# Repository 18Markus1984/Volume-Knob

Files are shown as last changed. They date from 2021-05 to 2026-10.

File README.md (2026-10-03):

# Volume Knob V2 (USB-C)

A compact USB volume knob based on an **Arduino Pro Micro (USB-C)**. Turn it to change your computer's volume, click to mute – and eight RGB LEDs under a transparent ring give visual feedback with selectable colors and animations.

The knob shows up as a standard USB media keyboard, so it works on Windows, macOS and Linux without any drivers.



**3D-printable parts, photos and more:** [Printables – Volume Knob V2 (USB-C)](https://www.printables.com/model/154855-volume-knob-v2-usb-c)

---

## Features

- Volume up / down by turning the knob, mute by clicking it
- 8 addressable RGB LEDs (SK6812) behind a clear printed ring
- 25 selectable colors
- Several LED animation modes
- Color and mode are stored in EEPROM and survive unplugging
- USB-C, plug & play (USB HID consumer control)
- Roughly **€20** in parts per knob

## Bill of Materials

| Qty | Part | Notes |
|---:|---|---|
| 1 | Arduino Pro Micro (ATmega32U4, **USB-C**) | 5 V / 16 MHz |
| 8 | SK6812 RGB LED, 5050 package | WS2812B-compatible |
| 1 | ALPS rotary encoder with push switch | |
| 1 | 10 kΩ resistor | |
| 1 | Custom PCB | KiCad project and Gerbers in this repo |
| 4 | M3 × 16 screws | |
| 4 | M3 threaded inserts | |
| – | PLA + clear/transparent filament | for the housing and the light ring |

## 3D Printing

All parts print fine in **PLA**. Print the **light ring in transparent filament** so the LEDs shine through. The bottom can optionally be printed with a decorative pattern – an *Octagram Spiral* top/bottom surface pattern looks great.

The print files are on [Printables](https://www.printables.com/model/154855-volume-knob-v2-usb-c); the source CAD files (Autodesk Inventor, STEP, STL) are in [`ProMicroKiCad-master/VolumeKnob/3DObjekt`](ProMicroKiCad-master/VolumeKnob/3DObjekt).

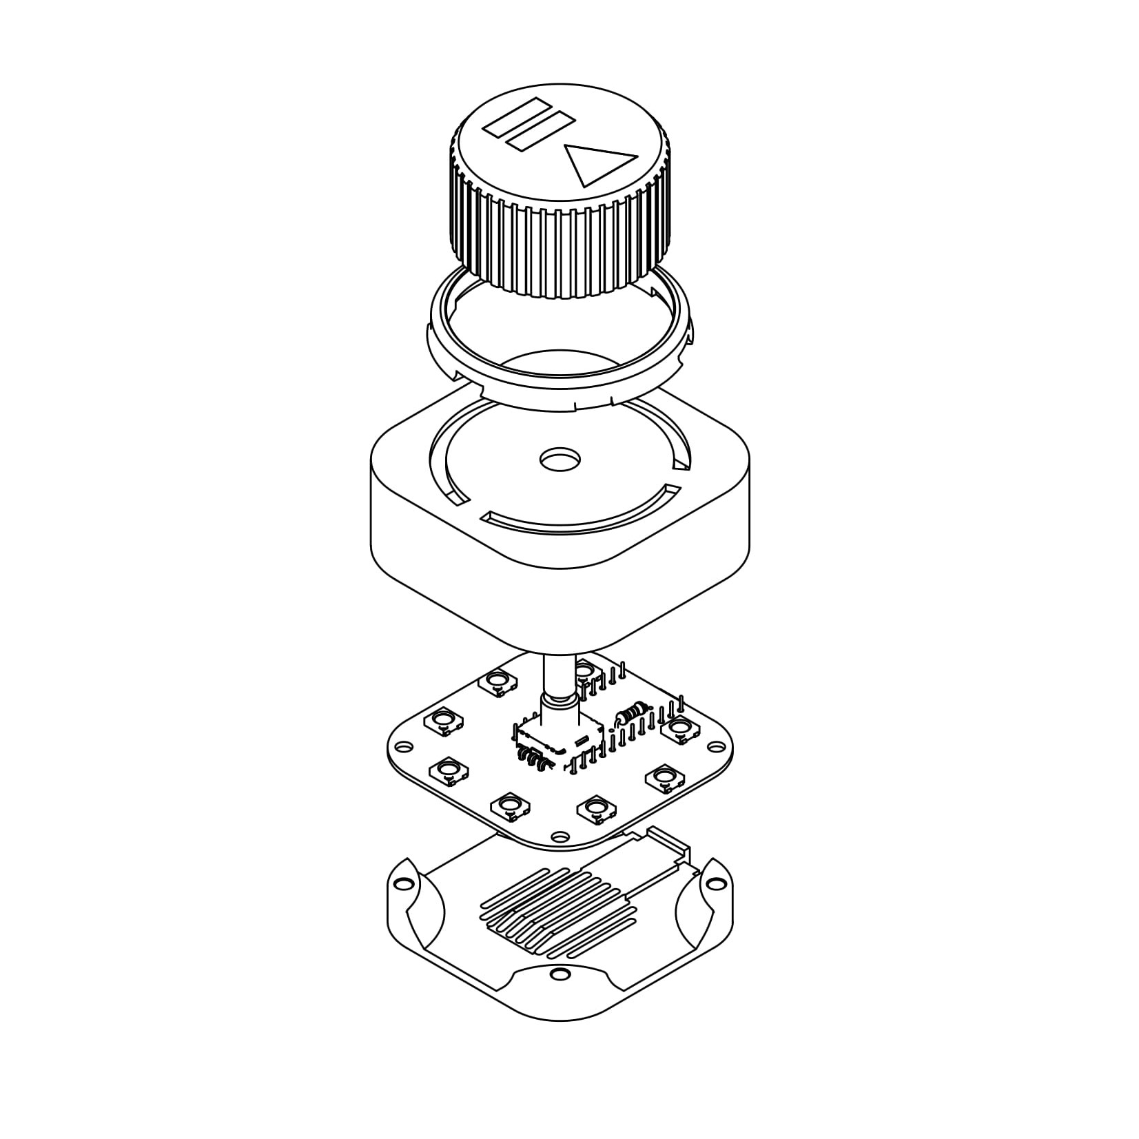
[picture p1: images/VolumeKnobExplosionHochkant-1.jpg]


## Assembly

1. Solder the rotary encoder, the Arduino Pro Micro and the resistor onto the PCB.
2. Melt the four M3 threaded inserts into the holes of the bottom housing.
3. Snap the transparent ring into the housing (snap-fit, no glue needed).
4. Fasten the PCB assembly with the four M3 screws.
5. Press the knob onto the encoder shaft – it's a press fit, no adhesive required.

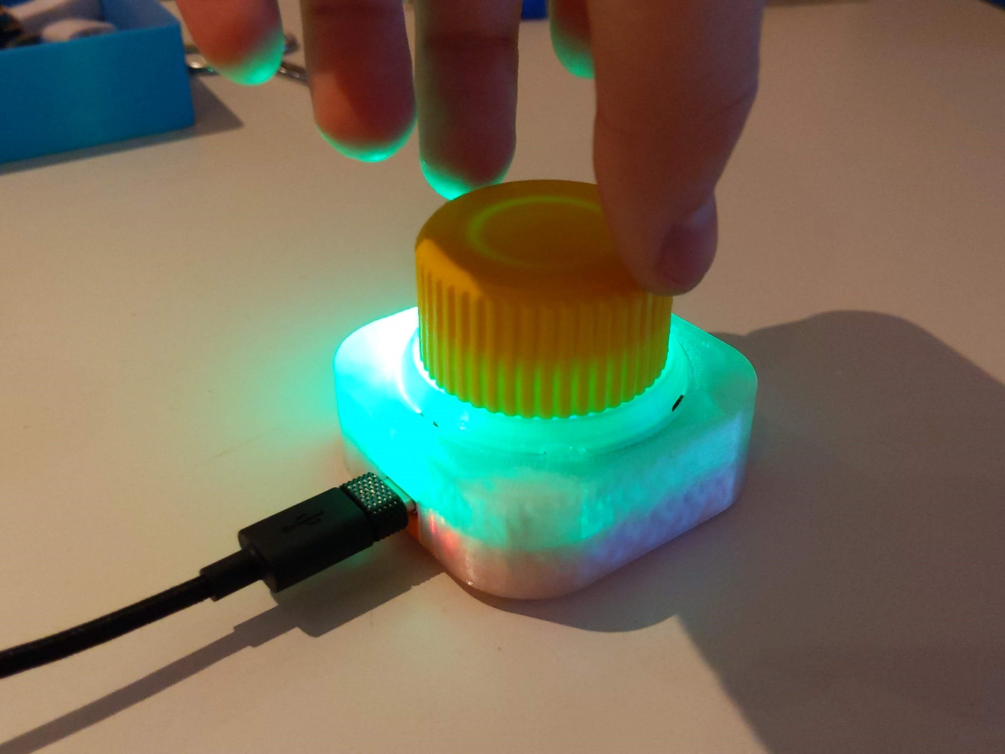
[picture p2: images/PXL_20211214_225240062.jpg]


## Wiring

| Pro Micro pin | Connected to |
|---:|---|
| 7 | LED data in (SK6812 chain) |
| 6 | Encoder CLK (A) |
| 5 | Encoder DT (B) |
| 2 | Encoder push button (SW) |

## Firmware

The sketch is located at [`volumeKnob/volumeKnob.ino`](volumeKnob/volumeKnob.ino).

### Required libraries

Install via the Arduino Library Manager:

- [HID-Project](https://github.com/NicoHood/HID) by NicoHood – USB media keys
- [Encoder](https://github.com/PaulStoffregen/Encoder) by Paul Stoffregen
- [Adafruit NeoPixel](https://github.com/adafruit/Adafruit_NeoPixel)
- [OneButton](https://github.com/mathertel/OneButton) by Matthias Hertel
- EEPROM (included with the Arduino IDE)

### Upload

1. Select the board **Arduino Leonardo** (or *SparkFun Pro Micro, 5 V / 16 MHz* if you have the SparkFun board package installed).
2. Choose the correct port and upload.

If you use a different number of LEDs, change `NUMPIXELS` at the top of the sketch.

> **Note:** On startup the knob sends 50× *Volume Down* followed by 2× *Volume Up*, so your system volume is set to a low, known level every time it is plugged in.

## Usage

| Action | Volume mode | Color menu | Mode menu |
|---|---|---|---|
| **Turn** | Volume up / down | Browse the 25 colors | Browse the animation modes |
| **Click** | Mute / unmute | Save color & go back | Save mode & go back |
| **Long press** | Open color menu | Open mode menu | Back to volume mode (without saving) |

Two encoder detents equal one volume step.

### LED modes

- **Single pixel** – one LED follows the knob and slowly fades out
- **Rainbow fade** – all LEDs fade through the color wheel
- **Rainbow wheel** – a rotating rainbow around the ring
- **Pixel trail** – three LEDs follow the knob and stay lit

In the mode menu the modes are arranged in groups around the ring, separated by a dark position.

## Repository Structure

```
Volume-Knob/
├── volumeKnob/volumeKnob.ino          # current firmware (V2)
├── images/                            # photos and GIFs
└── ProMicroKiCad-master/
    ├── VolumeKnob/
    │   ├── VolumeKnob.kicad_pro/_sch/_pcb   # KiCad project of the PCB
    │   ├── jlcpcb/                     # Gerber, BOM & CPL for JLCPCB
    │   ├── Gerber/                     # older Gerber revisions
    │   ├── 3DObjekt/                   # Inventor / STEP / STL files
    │   └── Code/                       # older sketches and test code
    └── ProMicroKiCad-master/           # Pro Micro KiCad library
```

## Gallery

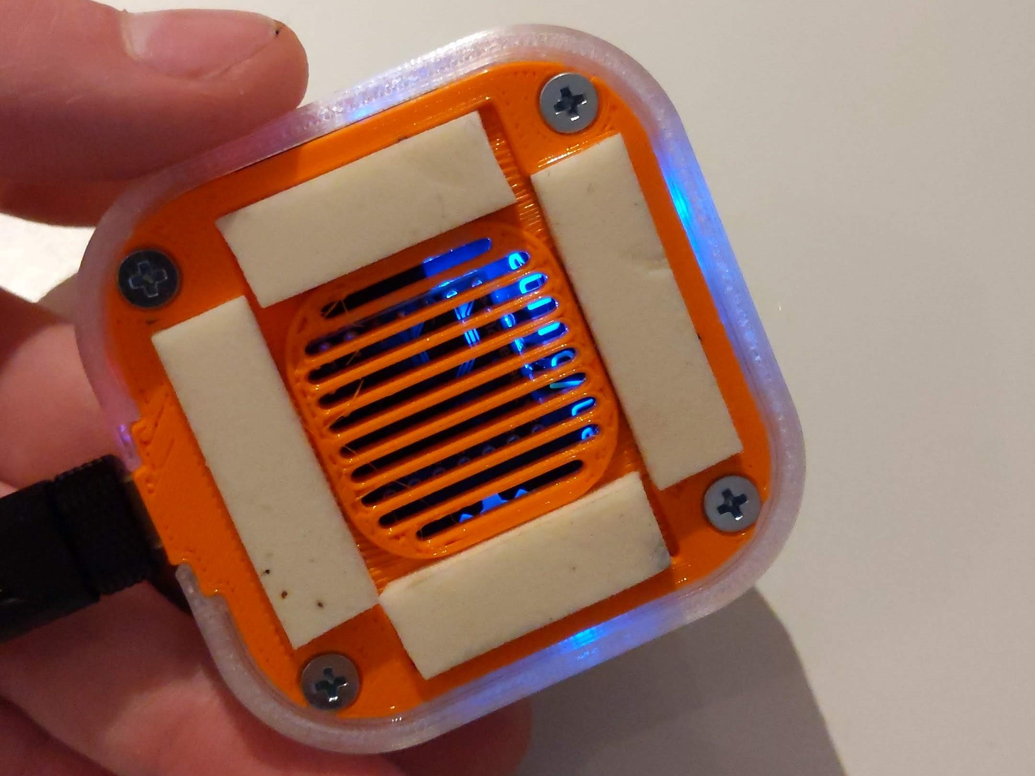
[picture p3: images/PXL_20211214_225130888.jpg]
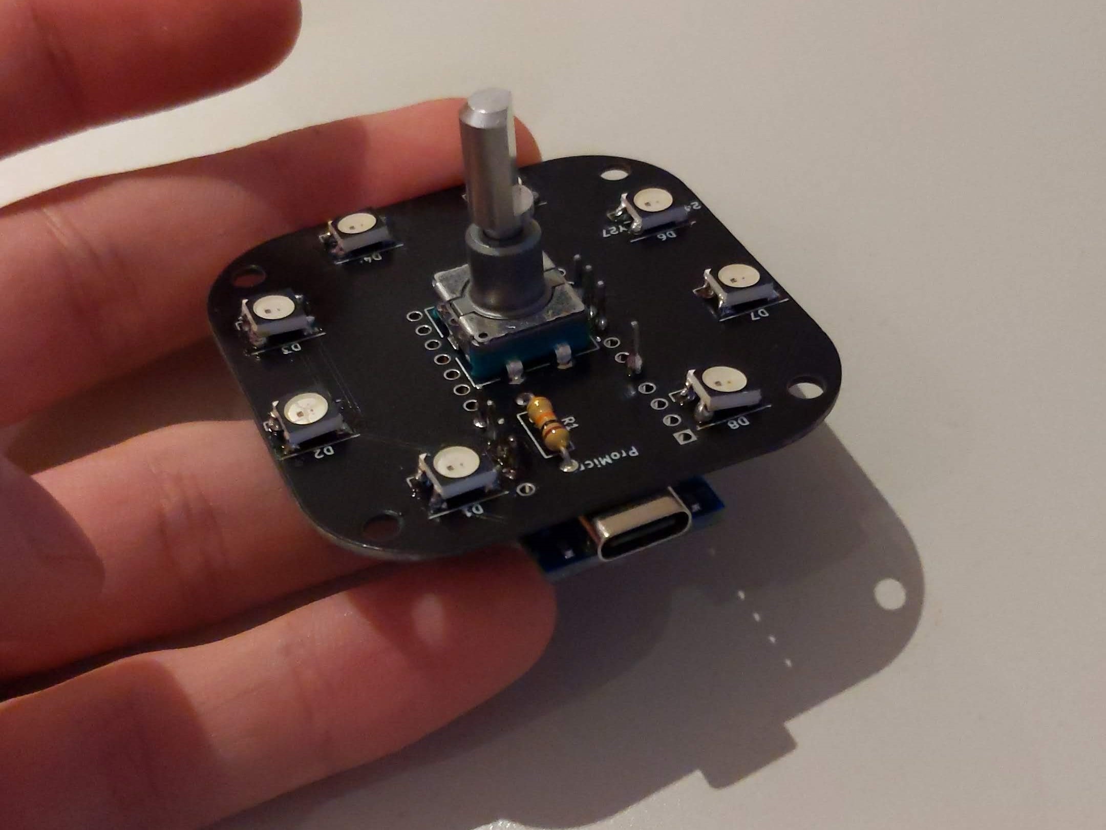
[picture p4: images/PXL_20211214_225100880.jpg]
 

## Version 1

The first version used a micro-USB Pro Micro, single-color green LEDs and a hand-wired build (8× green LEDs, 2× 10 kΩ resistors). Using individual LEDs instead of a ring PCB wasn't the best idea – it took some hot glue to hold everything in place – which led to the V2 with a custom PCB, RGB LEDs and USB-C.

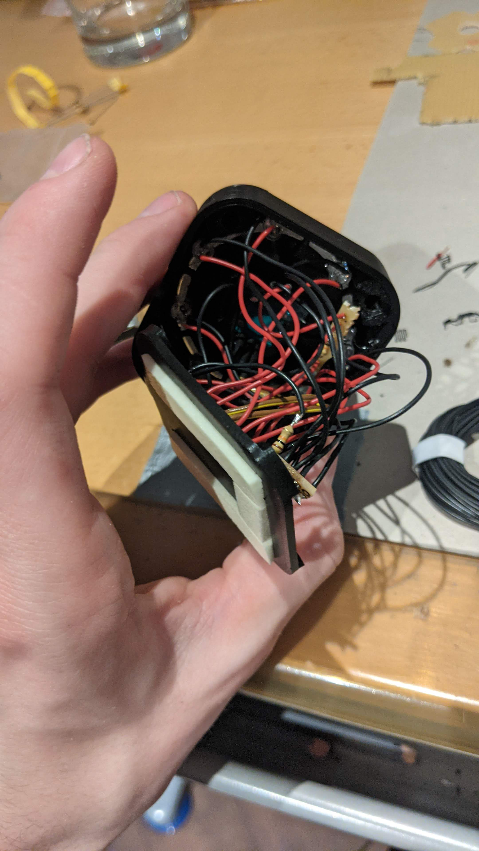
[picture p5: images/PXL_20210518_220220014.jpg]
 

---

Made by **Max Siebenschläfer** – find more projects on [Printables](https://www.printables.com/model/154855-volume-knob-v2-usb-c).

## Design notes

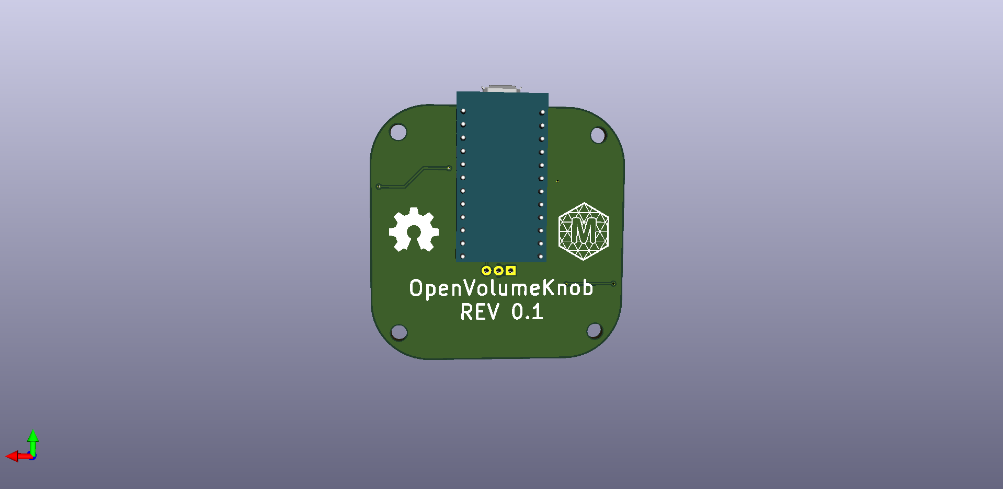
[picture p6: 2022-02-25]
ProMicroKiCad-master/VolumeKnob/images/VolumeKnob2.png

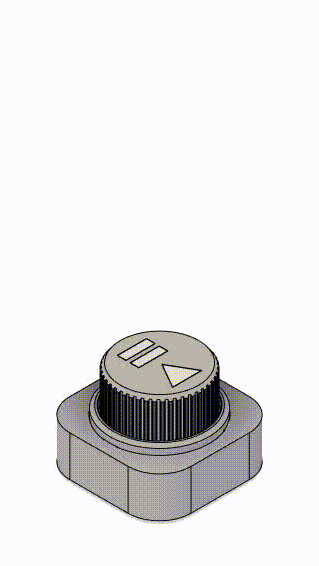
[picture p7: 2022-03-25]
images/ezgif-1-fd4612bca2.gif

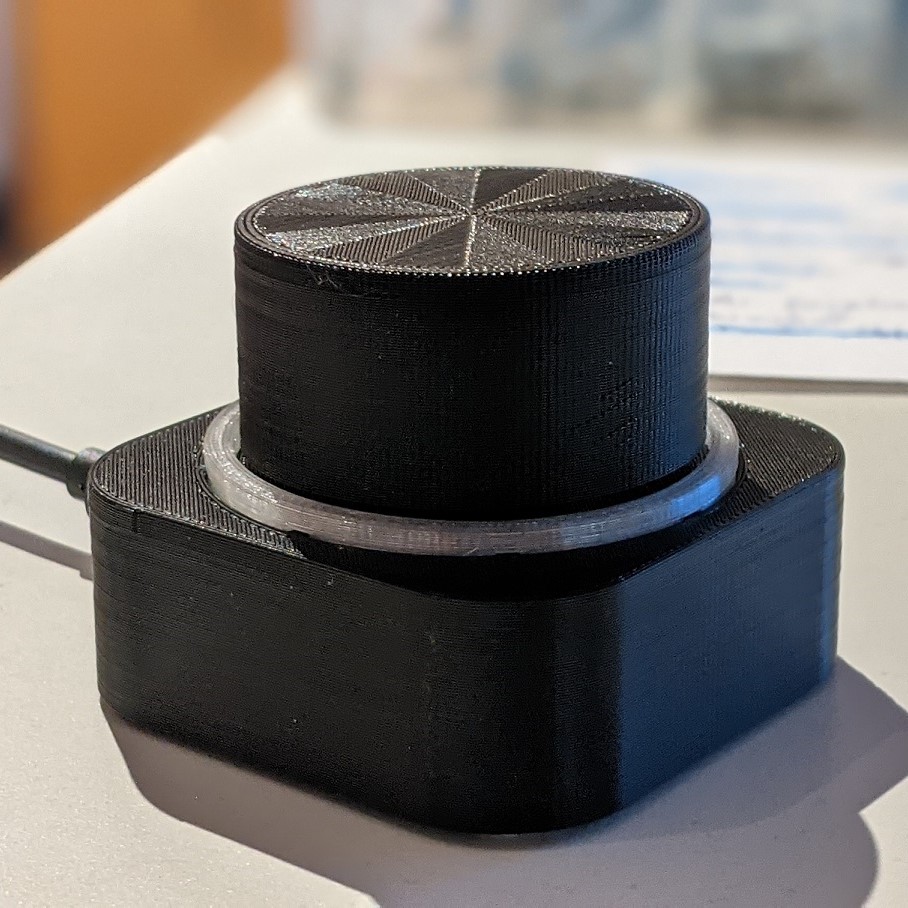
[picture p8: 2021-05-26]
images/PXL_20210518_190823981.PORTRAIT.jpg

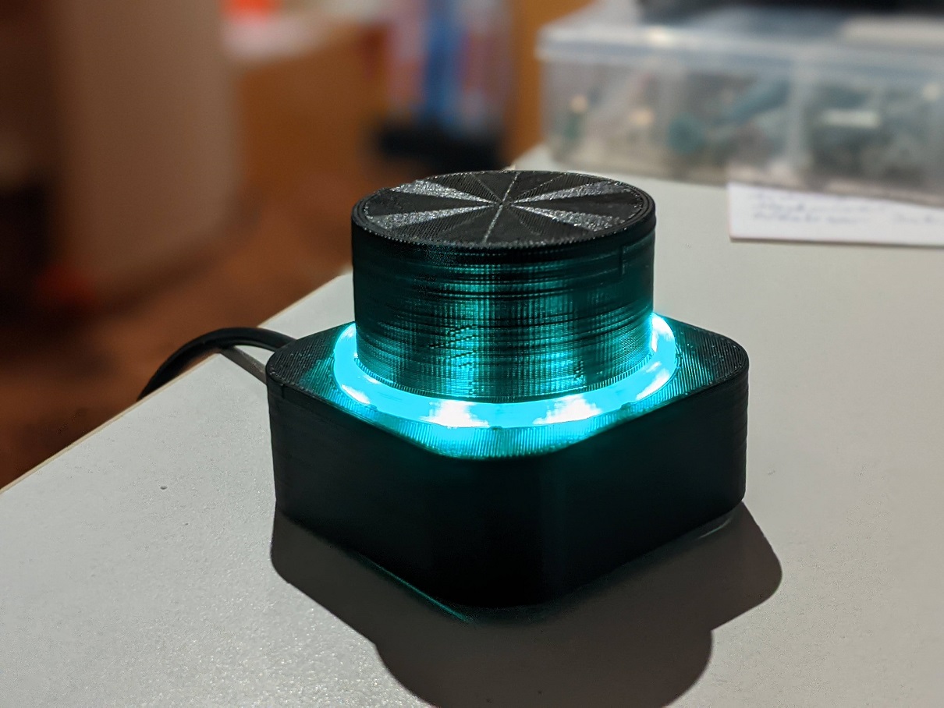
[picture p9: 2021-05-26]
images/PXL_20210525_201555468.PORTRAIT.jpg

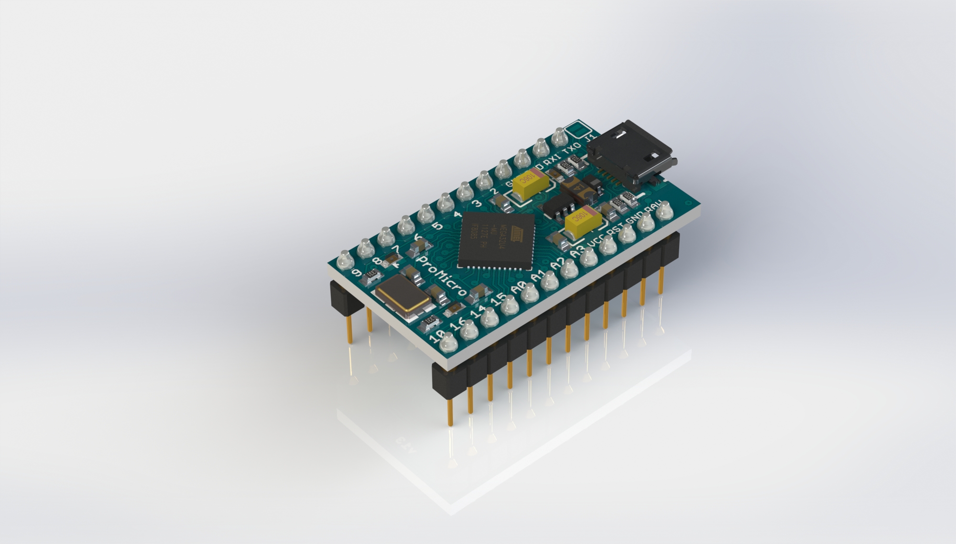
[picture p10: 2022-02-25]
ProMicroKiCad-master/arduino-pro-micro-1.snapshot.1/PROMICRO 1.JPG

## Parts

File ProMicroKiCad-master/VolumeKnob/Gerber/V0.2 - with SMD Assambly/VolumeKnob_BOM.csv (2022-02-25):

Comment | Designator | Footprint | LCSC
SK6812 | D1,D2,D3,D4,D5,D6,D7,D8 | LED_SMD:LED_SK6812_PLCC4_5.0x5.0mm_P3.2mm
10 kΩ | R1 | Resistor_THT:R_Axial_DIN0207_L6.3mm_D2.5mm_P10.16mm_Horizontal
Rotary_Encoder_Switch | SW1 | Rotary_Encoder:RotaryEncoder_Alps_EC12E-Switch_Vertical_H20mm
ProMicro | U1 | promicro:ProMicro-NoSilk

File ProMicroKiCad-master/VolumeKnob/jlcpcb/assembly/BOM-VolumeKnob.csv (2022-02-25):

Comment | Designator | Footprint | LCSC
WS2812B | D1,D10,D11,D12,D13,D14,D15,D16,D17,D18,D19,D2,D20,D21,D22,D23,D24,D25,D26,D27,D28,D29,D3,D30,D31,D32,D33,D34,D35,D36,D4,D5,D6,D7,D8,D9 | LED_WS2812B_PLCC4_5.0x5.0mm_P3.2mm | C114586

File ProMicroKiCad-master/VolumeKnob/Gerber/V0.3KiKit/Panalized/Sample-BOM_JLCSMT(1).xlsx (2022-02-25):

Comment | Designator | Footprint | JLCPCB Part #（optional）
WS2812B | D1,D2,D3,D4,D5,D6,D7,D8,D9 | LED_SMD:LED_WS2812B_PLCC4_5.0x5.0mm_P3.2mm | C114586

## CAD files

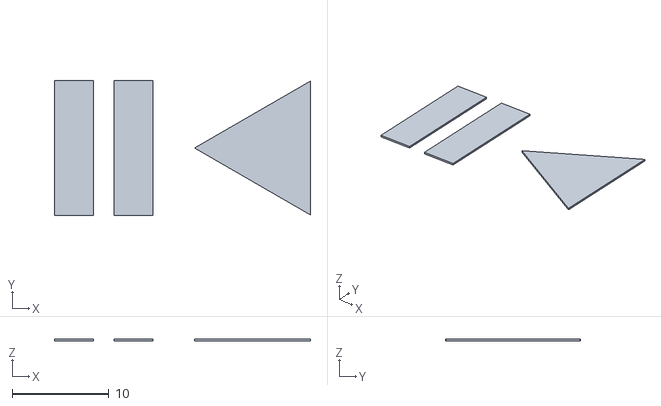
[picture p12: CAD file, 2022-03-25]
ProMicroKiCad-master/VolumeKnob/3DObjekt/Pause.stl
26.4 x 13.9 x 0.2

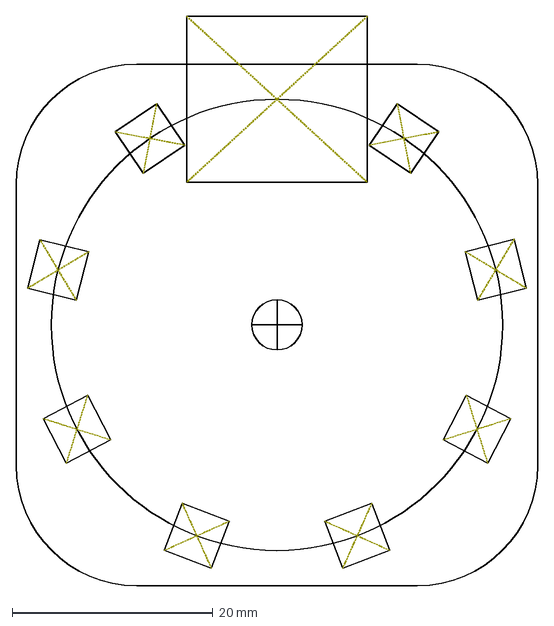
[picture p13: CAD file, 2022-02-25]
ProMicroKiCad-master/VolumeKnob/BackUpBevorKiKit/Grundform.dxf
52.0 x 56.8 mm

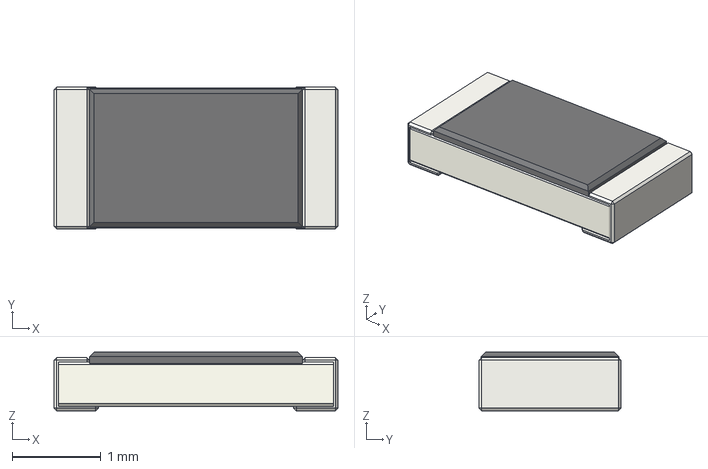
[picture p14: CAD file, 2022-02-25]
ProMicroKiCad-master/VolumeKnob/kicad3Dmodels-master/kicad3Dmodels-master/generated/Resistors/Chip/RESC3216x66_EIA1206_METRIC3216.step
3.20 x 1.60 x 0.66 mm

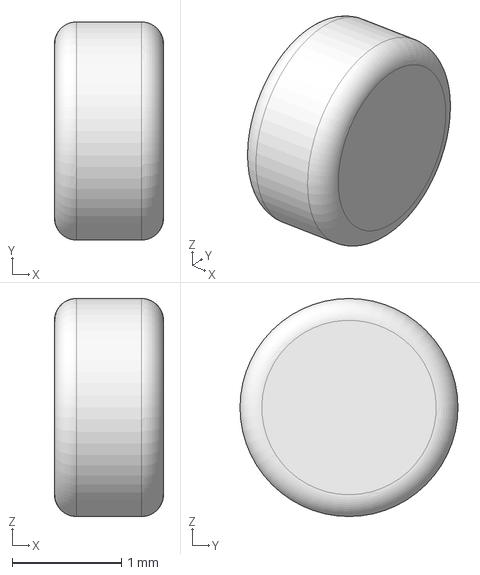
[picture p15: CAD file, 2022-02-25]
ProMicroKiCad-master/VolumeKnob/kicad3Dmodels-master/kicad3Dmodels-master/generated/Resistors/Film_Carbon/unitary_ring.fcstd
1.00 x 2.00 x 2.00 mm

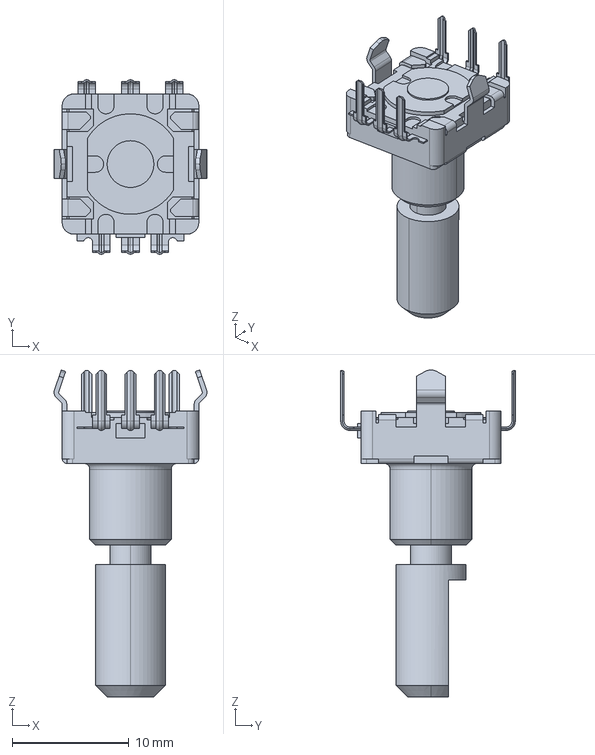
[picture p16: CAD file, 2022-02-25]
ProMicroKiCad-master/VolumeKnob/Objekts/RotaryEncoder.stp
13.1 x 15.0 x 28.0 mm

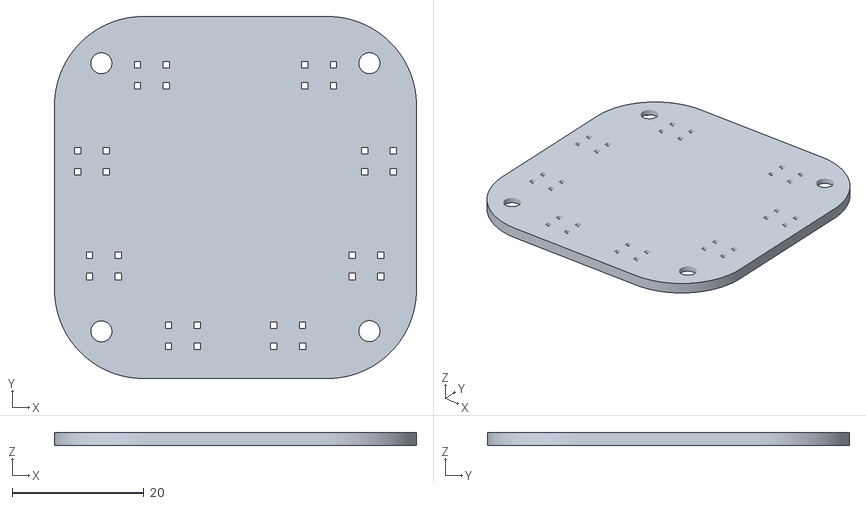
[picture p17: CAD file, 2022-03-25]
ProMicroKiCad-master/VolumeKnob/3DObjekt/Stencil.stl
55.0 x 55.0 x 2.00

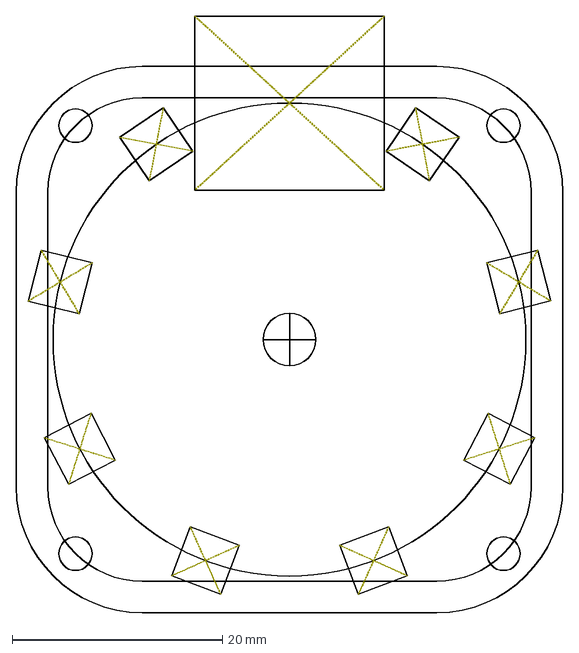
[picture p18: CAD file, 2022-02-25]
ProMicroKiCad-master/VolumeKnob/BackUpBevorKiKit/GrundformBorlöcher.dxf
52.0 x 56.8 mm

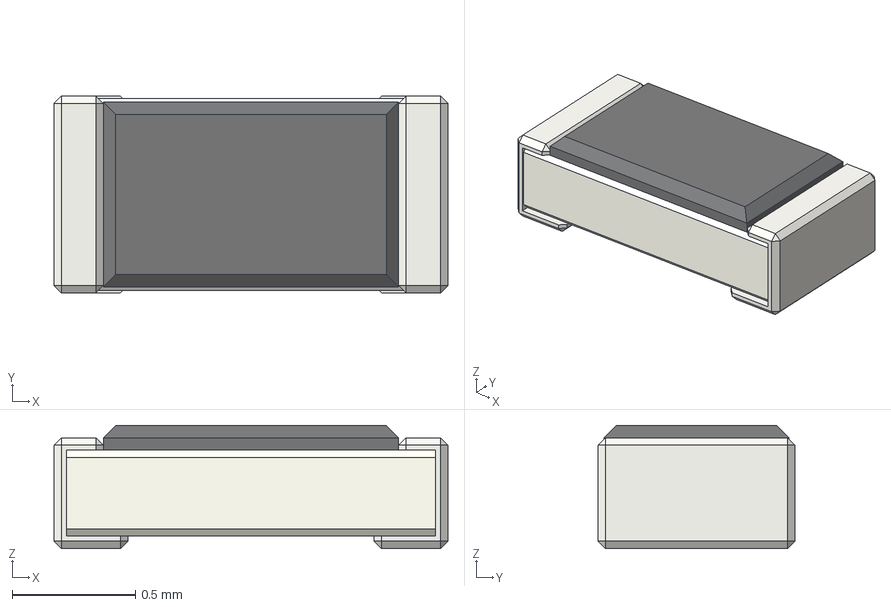
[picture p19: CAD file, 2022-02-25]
ProMicroKiCad-master/VolumeKnob/kicad3Dmodels-master/kicad3Dmodels-master/generated/Resistors/Chip/RESC1608X50_EIA0603_METRIC1608.step
1.60 x 0.8 x 0.5 mm

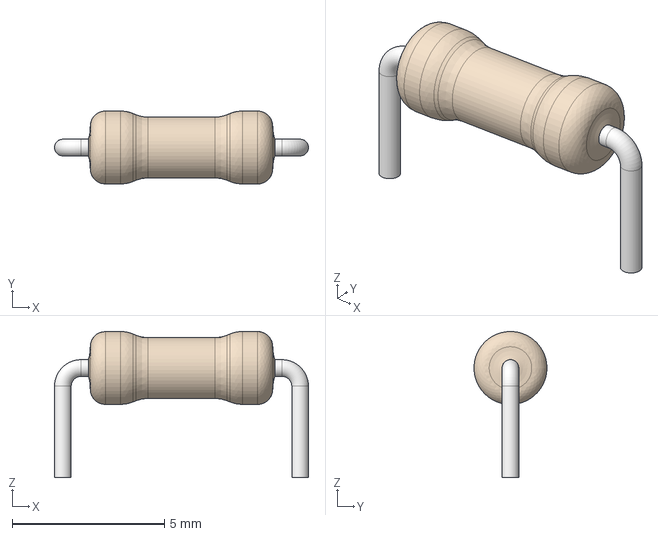
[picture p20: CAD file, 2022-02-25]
ProMicroKiCad-master/VolumeKnob/kicad3Dmodels-master/kicad3Dmodels-master/generated/Resistors/Film_Carbon/RESAD780W55L630D240B.step
8.35 x 2.40 x 4.80 mm

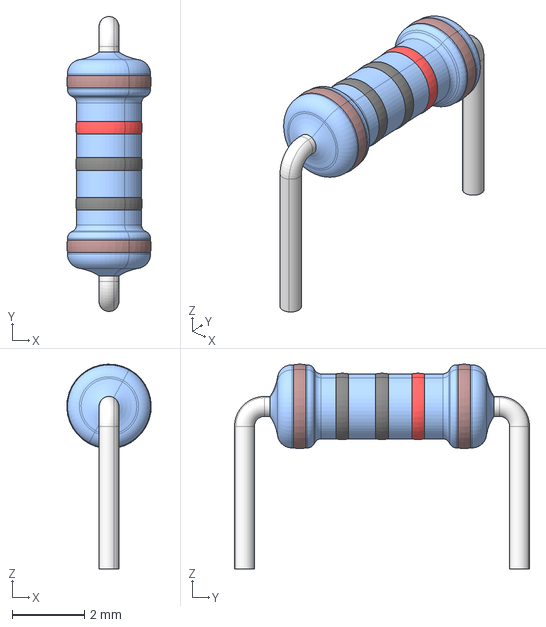
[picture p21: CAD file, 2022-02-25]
ProMicroKiCad-master/VolumeKnob/Objekts/Resistor_10K Ohm_tol1pct_0,25W__07,62.stp
2.34 x 8.17 x 5.67 mm

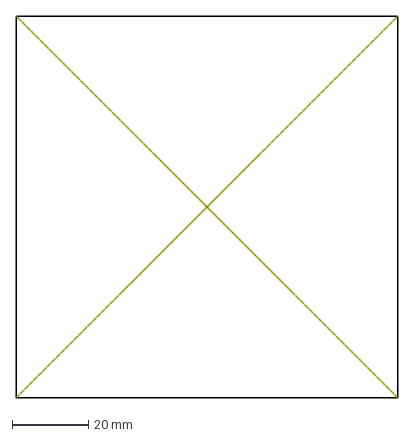
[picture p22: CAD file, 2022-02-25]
ProMicroKiCad-master/VolumeKnob/PanalizeOutline.dxf
100.0 x 100.0 mm

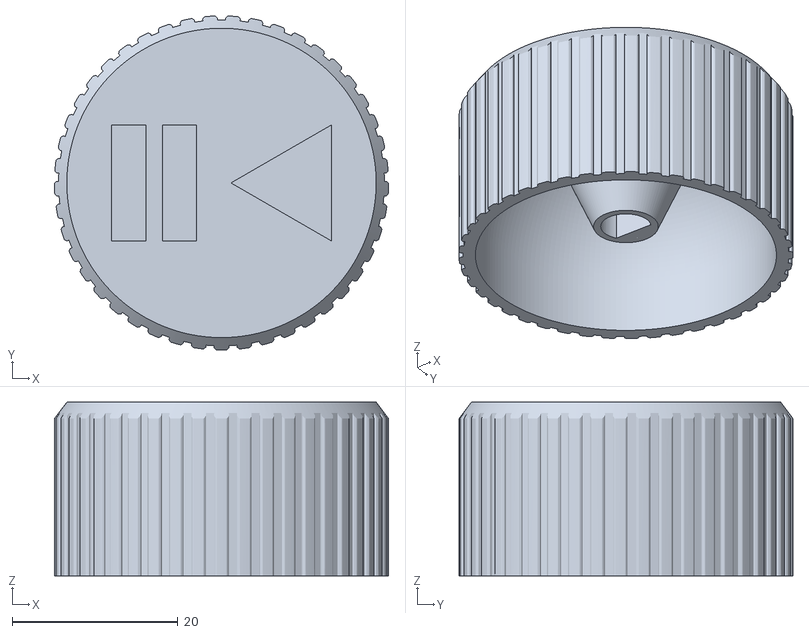
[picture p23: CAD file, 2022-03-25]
ProMicroKiCad-master/VolumeKnob/3DObjekt/DrehreglerWithPause.stl
40.4 x 40.4 x 21.0

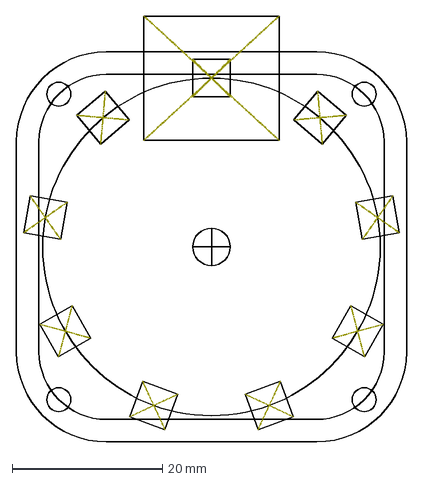
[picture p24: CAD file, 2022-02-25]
ProMicroKiCad-master/VolumeKnob/BackUpBevorKiKit/GrundformPlatineLEDs.dxf
52.0 x 56.8 mm

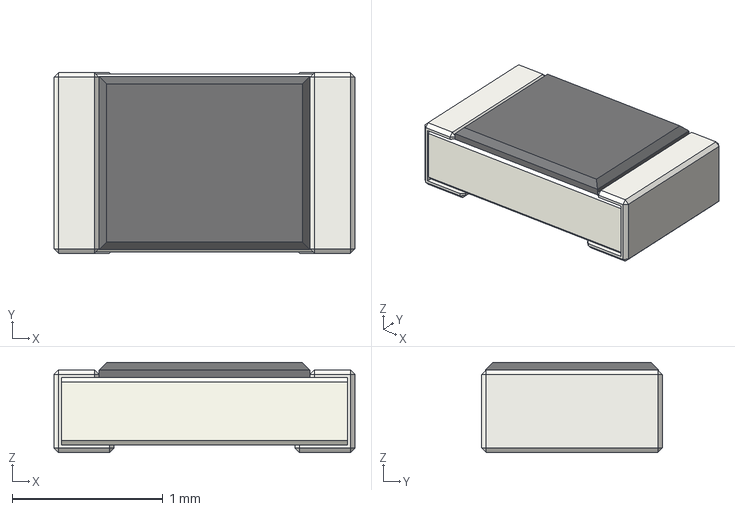
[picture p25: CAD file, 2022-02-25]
ProMicroKiCad-master/VolumeKnob/kicad3Dmodels-master/kicad3Dmodels-master/generated/Resistors/Chip/RESC2012X65_EIA0805_METRIC2012.step
2.00 x 1.20 x 0.6 mm

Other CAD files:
ProMicroKiCad-master/VolumeKnob/Objekts/RotaryEncoderV2.stp
ProMicroKiCad-master/VolumeKnob/3DObjekt/PCB-Holder.stl
ProMicroKiCad-master/VolumeKnob/3DObjekt/ArduinoProMicroButtomSoldered.iam
ProMicroKiCad-master/VolumeKnob/3DObjekt/Bodenplatte(USB-C).stl
ProMicroKiCad-master/VolumeKnob/3DObjekt/Bodenplatte.ipt
ProMicroKiCad-master/VolumeKnob/3DObjekt/Bodenplatte.stl
ProMicroKiCad-master/VolumeKnob/3DObjekt/COMPOUND.ipt
ProMicroKiCad-master/VolumeKnob/3DObjekt/COMPOUND_2.ipt
ProMicroKiCad-master/VolumeKnob/3DObjekt/Drehregler - Kopie.ipt
ProMicroKiCad-master/VolumeKnob/3DObjekt/Drehregler.ipt
ProMicroKiCad-master/VolumeKnob/3DObjekt/Drehregler.stl
ProMicroKiCad-master/VolumeKnob/3DObjekt/LED_SK6812_PLCC4_5.0x5.0mm_P3.2mm.iam
ProMicroKiCad-master/VolumeKnob/3DObjekt/Oberbau(USB-C).stl
ProMicroKiCad-master/VolumeKnob/3DObjekt/Oberbau.ipt
ProMicroKiCad-master/VolumeKnob/3DObjekt/Oberbau.stl
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

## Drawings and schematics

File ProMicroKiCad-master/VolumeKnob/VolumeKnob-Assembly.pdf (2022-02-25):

1 1 | 2 | 3 | 4 | 5 | 6

A

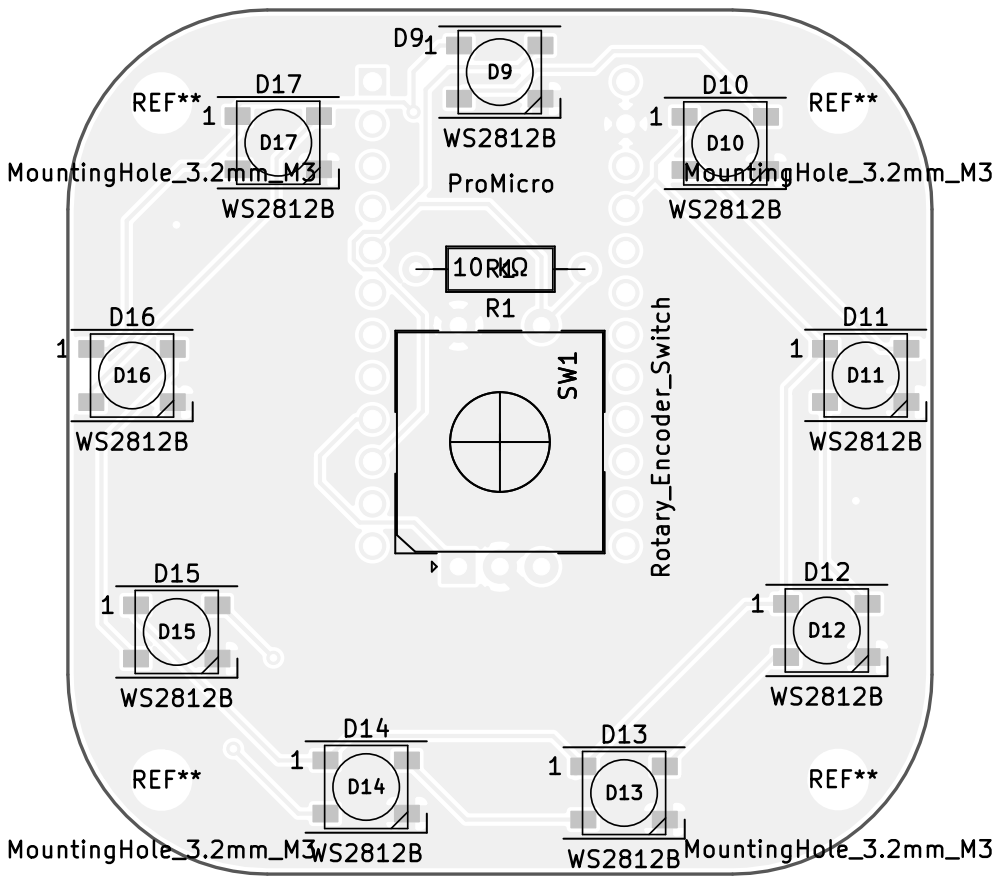
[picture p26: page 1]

1 | 2 | 3 | 4 | 5 | 6

A

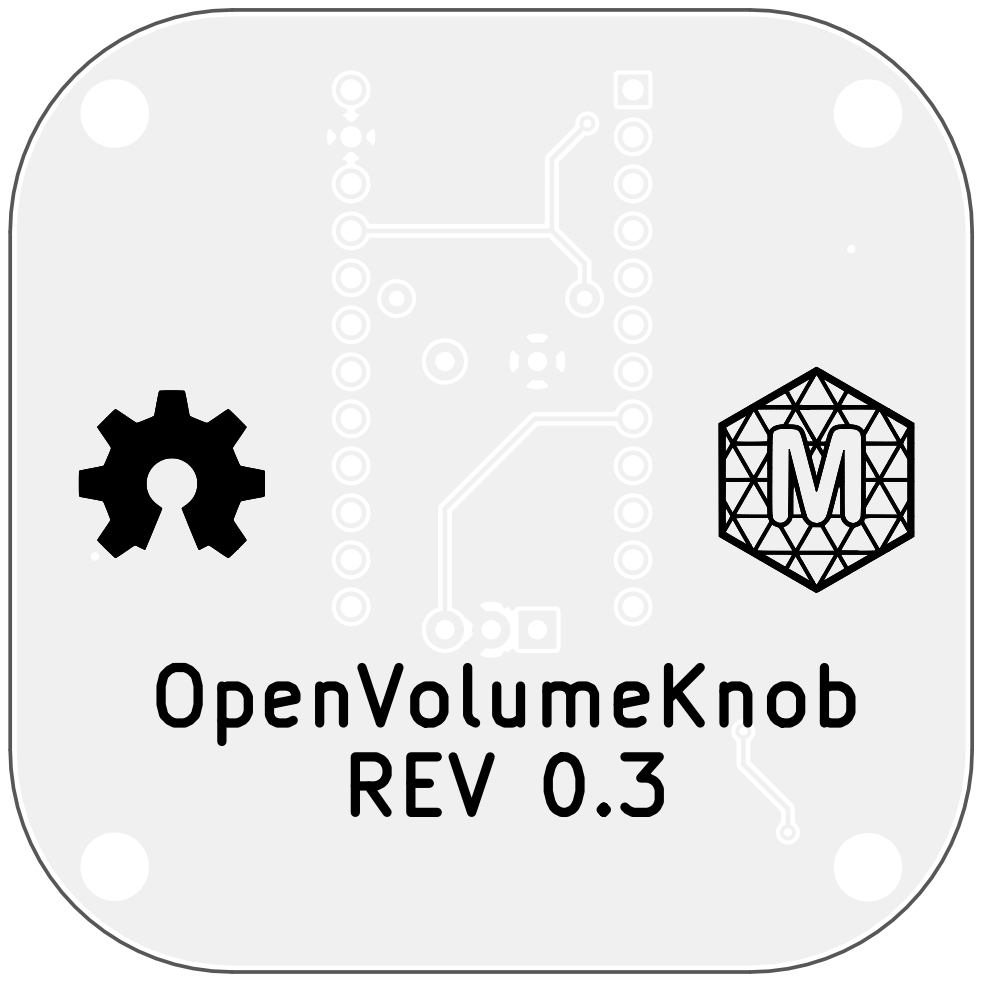
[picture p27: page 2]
OpenVolumeKnob REV 0.3; D Date: KiCad E.D.A. kicad (6.0.0) Size: A4; Rev:; Id: 1/1 Title:; File: VolumeKnob.kicad_pcb; Sheet: Assembly

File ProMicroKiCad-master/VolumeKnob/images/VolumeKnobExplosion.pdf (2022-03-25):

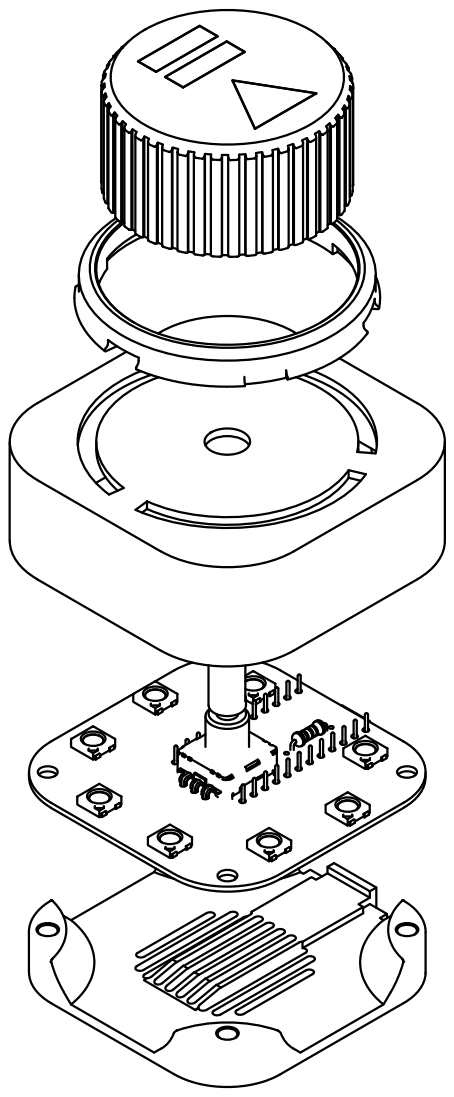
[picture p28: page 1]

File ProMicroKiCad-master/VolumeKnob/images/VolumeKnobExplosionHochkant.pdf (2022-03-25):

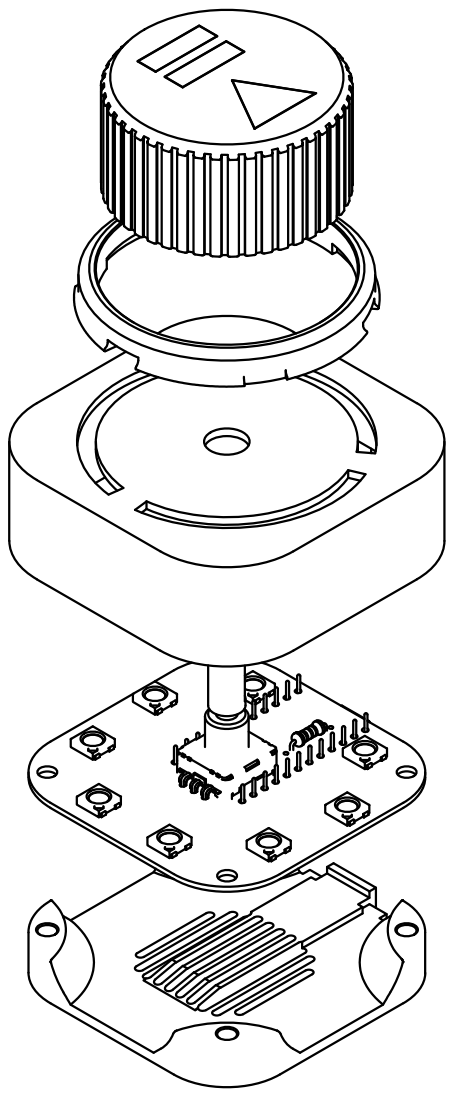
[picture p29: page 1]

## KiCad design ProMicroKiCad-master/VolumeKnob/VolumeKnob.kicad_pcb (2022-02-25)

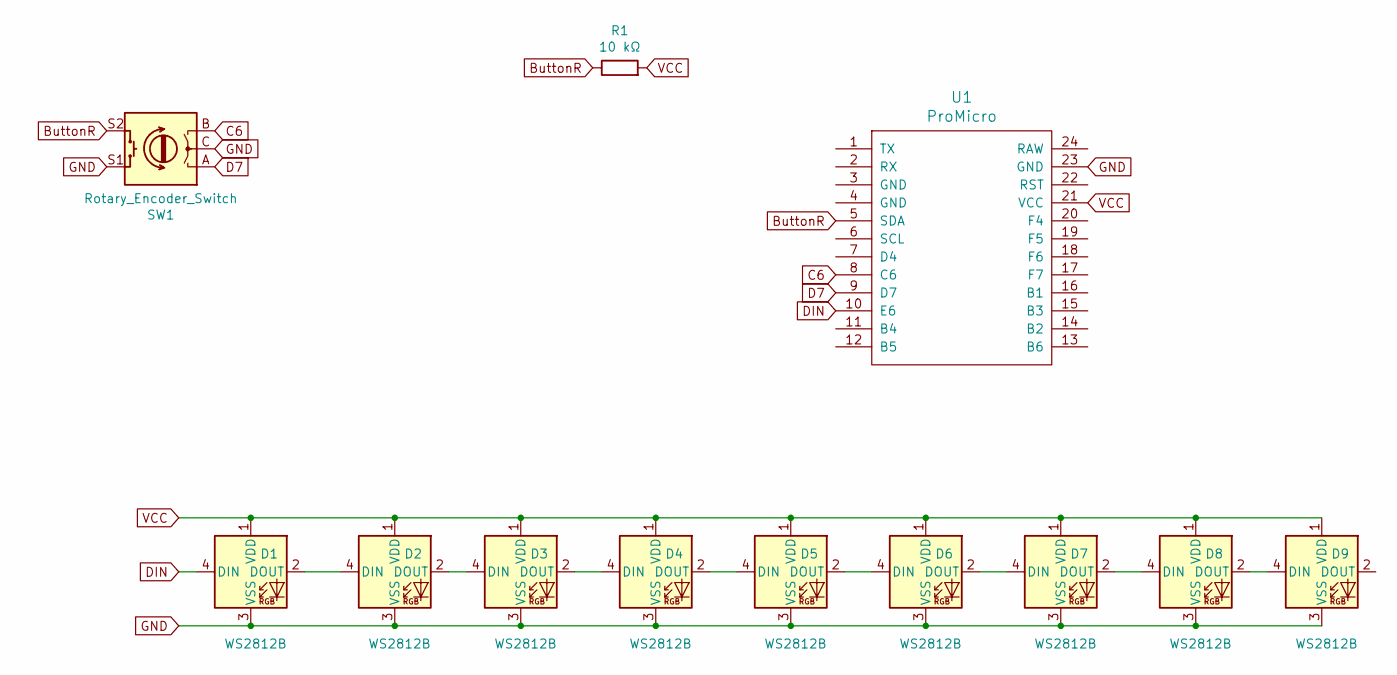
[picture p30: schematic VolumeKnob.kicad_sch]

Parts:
D1, D2, D3, D4, D5, D6, D7, D8, D9: WS2812B; LED_WS2812B_PLCC4_5.0x5.0mm_P3.2mm; LCSC C114586
R1: 10 kΩ; R_Axial_DIN0207_L6.3mm_D2.5mm_P10.16mm_Horizontal
SW1: Rotary_Encoder_Switch; RotaryEncoder_Alps_EC12E-Switch_Vertical_H20mm
U1: ProMicro; ProMicro-NoSilk

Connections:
ButtonR: R1.1, SW1.S2, U1.5 (SDA)
C6: SW1.B, U1.8 (C6)
D7: SW1.A, U1.9 (D7)
DIN: D1.4 (DIN), U1.10 (E6)
GND: D1.3 (VSS), D2.3 (VSS), D3.3 (VSS), D4.3 (VSS), D5.3 (VSS), D6.3 (VSS), D7.3 (VSS), D8.3 (VSS), D9.3 (VSS), SW1.C, SW1.S1, U1.23 (GND)
unnamed: D1.2 (DOUT), D2.4 (DIN)
unnamed: D2.2 (DOUT), D3.4 (DIN)
unnamed: D3.2 (DOUT), D4.4 (DIN)
unnamed: D4.2 (DOUT), D5.4 (DIN)
unnamed: D5.2 (DOUT), D6.4 (DIN)
unnamed: D6.2 (DOUT), D7.4 (DIN)
unnamed: D7.2 (DOUT), D8.4 (DIN)
unnamed: D8.2 (DOUT), D9.4 (DIN)
VCC: D1.1 (VDD), D2.1 (VDD), D3.1 (VDD), D4.1 (VDD), D5.1 (VDD), D6.1 (VDD), D7.1 (VDD), D8.1 (VDD), D9.1 (VDD), R1.2, U1.21 (VCC)

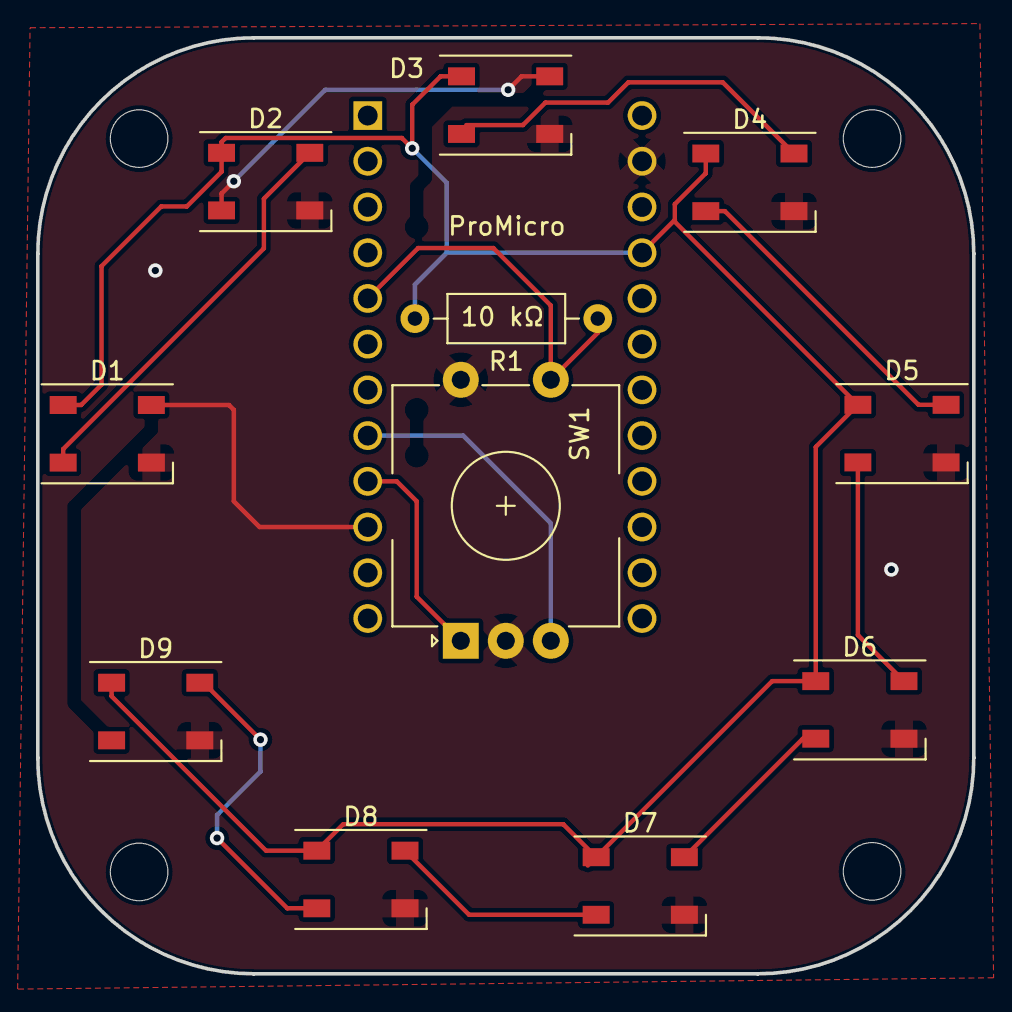
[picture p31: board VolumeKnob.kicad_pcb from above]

Board: 2 copper layers, 52.0 x 52.0 mm, 12 parts (0 on the bottom side), 14 nets.

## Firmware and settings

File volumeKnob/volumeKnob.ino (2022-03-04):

#include <HID-Project.h>
#include <Encoder.h>
#include <Adafruit_NeoPixel.h>
#include <OneButton.h>
#include <EEPROM.h>

#define PIN       7 //Datapin for the LEDs
#define NUMPIXELS 8 //number of LEDs in the row

//Color Options
byte color[25][3] = {{255,0,0},{255,64,0},{255,128,0},{255,191,0},{255,255,0},{191,255,0},{128,255,0},{64,255,0},{0,255,0},{0,255,64},{0,255,128},{0,255,191},{0,255,255},{0,191,255},
{0,128,255},{0,64,255},{0,0,255},{64,0,255},{128,0,255},{191,0,255},{255,0,255},{255,0,191},{255,0,128},{255,0,64},{255,0,0}};  //Array with the different color-values would be better to do this with a function
int row = 0;  //pointer, which color is selected ##das is kein Pointer

//Rotary Encoder
const int CLK = 6;//Clockpin Encoder         
const int DT = 5; //Datepin Encoder
const int SW = 2; //Button of the Encoders
int pos = 0;    //the variable for the Encoder-function to give back 
long oldPosition = -999;   //position for the rotary encoder
bool turnLeft = false;      //State for turning left //I use this variables to check that you have to move two incerements to get one move in the volume 
bool turnRight = false;      //State for turning right

//variable for the first mode
int newPos = 0;   //the selected LED that should light up
int oldpos = 0;   //the last lit up LED, You need this to turn the LED off after you jump to the next one ##Name nicht eindeutig, oldPosition-oldpos

//Rainbow-Mode
uint16_t r, m;

//Florian-Mode
byte florian[3][3] = {{0,255,0},{255,255,0},{255,0,0}}; //green yellow red for the traffic light mode
int volumeInPercent = 0;

//Settings-menu
int menu = 0; //0 = Sound-Mode, 1 = color selection, 2 = modi-selection
int mode = 1; //1-7 = Rotating-Pixel, 9-15 = rgb-wheel fade, 17-23 = rgb-wheel with the moving colors, 25-31 = percent red, yellow, green for different noise levels, 33-39 = simular to the first mode but you have 3 LEDs and the pixels stay on
int brightness = 255; //of LEDs from 0-255

//Generall Objects
OneButton EncoderSwitch(SW,true);   //Libary that adds functions for LongPress, DoubleClick etc.
Encoder myEncoder(DT,CLK);      
Adafruit_NeoPixel pixels(NUMPIXELS, PIN, NEO_GRB + NEO_KHZ800);

void setup();
void loop();
void volumeControl();
void colorSelection();
void modeSelection();
void showPixels();
void onePixelFade();
void rgbWheelFade();
void rgbWheelMoving();
void pixelFadeStay();
void clicked();
void longPress();
int TurnEncoder(int len);
uint32_t Wheel(byte WheelPos);
void resetLEDs();
void lightAll(int r, int g, int b);

void setup(){
  Serial.begin(9600);
  Serial.println("Consumer setup...");
  Consumer.begin();

  //Rotary Encoder with Switch
  Serial.println("Rotary Encoder setup...");
  pinMode(SW, INPUT);
  EncoderSwitch.attachClick(clicked);
  EncoderSwitch.attachLongPressStop(longPress);

  //LEDs
  pixels.begin();

  //Read saved settings
  row = EEPROM.read(0);   
  mode = EEPROM.read(1);

  for(int i = 0; i<50;i++){   //for a special mode doesn't work till now ##geht hier ein direktes auf 0 setzten nicht ?
    Consumer.write(MEDIA_VOL_DOWN);
  }
  Consumer.write(MEDIA_VOL_UP);
  Consumer.write(MEDIA_VOL_UP);
  volumeInPercent = 4;
}

void loop(){ 
  if(menu == 0){  
    volumeControl();
  } 
  else if (menu == 1) {   
    colorSelection();
  } 
  else if (menu == 2) {  
    modeSelection();
  }
  showPixels();
  EncoderSwitch.tick();   //the libary reads the encoder value and gives back an int ##dat gibt garnischt zurück. Also zumindest speicherst du es nicht ab
  delay(10); 
}

void volumeControl(){
  int i = TurnEncoder(NUMPIXELS);
    if(i != -1){ 
      newPos = i; 
      brightness = 255;           
      if(newPos > oldpos && newPos != NUMPIXELS-1 && oldpos != 0 || newPos == 0 && oldpos == NUMPIXELS-1){ //solves the issue from 0 to NUMPIXELS-1 and NUMPIXELS-1 to 0     
        Consumer.write(MEDIA_VOL_UP);   
        volumeInPercent -= 2;
        if(volumeInPercent < 0){
          volumeInPercent = 0;
        }
      }
      else if(newPos < oldpos && newPos != 0 && oldpos != NUMPIXELS-1 || newPos == NUMPIXELS-1 && oldpos == 0){
        Consumer.write(MEDIA_VOL_DOWN);
        volumeInPercent += 2;
        if(volumeInPercent>100) {
          volumeInPercent = 100;
        }
      } 
    }
}

void colorSelection(){
  int i = TurnEncoder(25);    //turns the Encoder with the length of the array
    if(i != -1){
      row = i;
      lightAll(color[row][0],color[row][1],color[row][2]);
    }
}

void modeSelection(){
  int i = TurnEncoder(NUMPIXELS*4);  //6 Positions for every mode with a blank spot between the modes
    if(i != -1){
      mode = i;
      brightness = 255;
    }
}


void showPixels(){    //function for the different Modis you could select
    if((menu == 0 || menu == 2 )&& mode > 0 && mode < NUMPIXELS){   //The first mode with only one pixel lit up that fades the color after some time
      onePixelFade();
    }
    else if((menu == 0 || menu == 2)&& mode > NUMPIXELS && mode < NUMPIXELS*2){   //the rgb-wheel fade
      rgbWheelFade();
    }
    else if((menu == 0 || menu == 2) && mode > NUMPIXELS*2 && mode < NUMPIXELS*3){//the rgb-wheel with the moving colors
      rgbWheelMoving();
    } 
    else if((menu == 0 || menu == 2) && mode > NUMPIXELS*3 && mode < NUMPIXELS*4){ //simular to the first mode but you have 3 LEDs and the pixels stay on.
      pixelFadeStay();
    }
    if(mode == NUMPIXELS || mode == NUMPIXELS*2 || mode == NUMPIXELS*3 || mode == NUMPIXELS*4 || mode == NUMPIXELS*5 || mode == 0 && menu == 2){  //The blank spots in the mode-menu where no animations should be shown
      resetLEDs();
    }
  pixels.setBrightness(brightness);
  pixels.show();    //Only time I update the pixels
}

void onePixelFade(){
  int value = 0;
  if(menu == 0){
        value = newPos;
      } 
      else if(menu == 2){
        value = mode;
      }
      if(value != -1 && (menu == 2 || menu == 0)){
          pixels.setPixelColor(oldpos, pixels.Color(0,0,0));
          pixels.setPixelColor(value, pixels.Color(color[row][0],color[row][1],color[row][2]));
          oldpos = value;
      }
      if(brightness <= 1){
        resetLEDs();
      }
      for(int i = 0; i < NUMPIXELS; i++){
        if(pixels.getPixelColor(i) != pixels.Color(0,0,0)){
          brightness = brightness - 1;
          i = NUMPIXELS;
        }
      }
}

void rgbWheelFade(){
  for(r = 0; r < NUMPIXELS; r++) {
        pixels.setPixelColor(r, Wheel((r+m) & 255));
      }
      m++;
      if(m >= 256) {
        m = 0;
      }
      oldpos = newPos;
}

void rgbWheelMoving(){
  for(r = 0; r < NUMPIXELS; r++) {
        pixels.setPixelColor(r,Wheel(((r * 256 / pixels.numPixels()) + m) & 255));
      }
      m++;
      if(m >= 256*5) {
        m = 0;
      }
      oldpos = newPos;
}


void pixelFadeStay(){
  int puffer = 0, value = 0;
  if(menu == 0){
        value = newPos;
      } 
      else if(menu == 2){
        value = mode - NUMPIXELS*4;
      }
      if(value != -1 && (menu == 2 || menu == 0)){
          pixels.fill(pixels.Color(0,0,0));
          for(int i = 0; i<3;i++) {
            puffer = value+i;
            if(puffer > NUMPIXELS-1){
              puffer = i-1;
            }
            pixels.setPixelColor(puffer, pixels.Color(color[row][0],color[row][1],color[row][2]));
          }
          oldpos = value;
      }
}

void clicked() {   //Select Button
  if(menu == 0){
    Consumer.write(MEDIA_VOL_MUTE);
    brightness = 255;
    pixels.fill(pixels.Color(color[row][0],color[row][1],color[row][2]));
    delay(700); 
  } 
  else if(menu == 1){   //leave the color-selection menu and select the color 
    Serial.println("leave with selected color");
    EEPROM.update(0,row);
    menu = 0;
    pos = 0;
    newPos = 0;
    oldpos = 0;
    oldPosition = -999;
    delay(100);    
  }
  else if(menu == 2){    //leave the mode-menu and select the mode
    Serial.print("leave with selected mode: ");
    Serial.println(mode);
    EEPROM.update(1,mode);
    pixels.clear();
    menu = 0;
    r = 0;
    m = 0; 
    pos = 0;
    newPos = 0;
    oldpos = 0;
    oldPosition = -999;
    delay(100);   
  }
}

void longPress() {    //Menu button
  menu++;   //jump into the next menu up
  pos = 0;
  newPos = 0;
  oldpos = 0;
  brightness = 255;
  resetLEDs();
  if(menu == 1){
    lightAll(color[row][0],color[row][1],color[row][2]);
  } 
  else if(menu == 2){
    row = EEPROM.read(0); 
    delay(100);  
  }
  if(menu >= 3){
    menu = 0;
    mode = EEPROM.read(1);
    r = 0;
    m = 0; 
    pos = 0;
    newPos = 0;
    oldpos = 0;
    oldPosition = -999;
  }
  Serial.print(menu);
  Serial.println("LongClick");
}

int TurnEncoder(int len) {      //The function that reads the data from the encoder relative to the given size. You can put in the len as the max number of points for one rotation
  long newPosition = myEncoder.read();   //read the position of the encoder
  if (newPosition != oldPosition){    //compare it to the old position
    if(newPosition > oldPosition){      //if the wheel turns left
      if(turnRight){       //turnLeft/Right are for reducing the number of points by half so you have to pass two points to get one, because the encoder roation points are sometimes pretty small
        pos++;
        if(pos == len){
          pos = 0;
        }        
        turnLeft = false;
        turnRight = false;
      }
      else {
        turnRight = true;
      }
    }
    else {   
       if(turnLeft){
        pos--;
        if(pos < 0){
          pos = len - 1;
        }
        turnRight = false;
        turnLeft = false;
       }else{
        turnLeft = true;
       }
    }
    oldPosition = newPosition; 
    return pos;
  }
  return -1;
}

uint32_t Wheel(byte WheelPos) {   //From the Adafruit Libyary a function for a rgb circle
  WheelPos = 255 - WheelPos;
  if(WheelPos < 85) {
    return pixels.Color(255 - WheelPos * 3, 0, WheelPos * 3);
  }
  if(WheelPos < 170) {
    WheelPos -= 85;
    return pixels.Color(0, WheelPos * 3, 255 - WheelPos * 3);
  }
  WheelPos -= 170;
  return pixels.Color(WheelPos * 3, 255 - WheelPos * 3, 0);
}

void resetLEDs(){
  pixels.clear();
}

void lightAll(int r, int g, int b) {
  pixels.fill(pixels.Color(r,g,b));
}

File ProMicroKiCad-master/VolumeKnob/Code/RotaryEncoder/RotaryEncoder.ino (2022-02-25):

#include <HID-Project.h>
#include <Encoder.h>
#include <Adafruit_NeoPixel.h>
#include <OneButton.h>
#include <Thread.h>
#include <ThreadController.h>
//#include <EEPROM.h>

#define PIN       7 //Datapin for the LEDs
#define NUMPIXELS 8 //Anzahl der LEDs

//Color Options
byte color[25][3] = {{255,0,0},{255,64,0},{255,128,0},{255,191,0},{255,255,0},{191,255,0},{128,255,0},{64,255,0},{0,255,0},{0,255,64},{0,255,128},{0,255,191},{0,255,255},{0,191,255},
{0,128,255},{0,64,255},{0,0,255},{64,0,255},{128,0,255},{191,0,255},{255,0,255},{255,0,191},{255,0,128},{255,0,64},{255,0,0}};
int row = 0;

//Rotary Encoder
const int CLK = 6;//Datapin Encoder         
const int DT = 5; //Datepin Encoder
const int SW = 2; //Button des Encoders

int pos = 0;    //the selected Led
int  brightness = 255; //Helligkeit der LEDs
long myTimer = 0;
long myTimeout = 5000;    //timer when the lights should turn off
bool timer1 = false;      //State for turning left
bool timer2 = false;      //State for turning right
long altePosition = -999;   //position for the rotary encoder

//Settings-menu
int menue = 0;
int selected = 0;

//Settings
int sec = 0;
uint8_t wait = 20;
int NumbPixel = 0; //Max Pixel = 7 und Min Pixel = 1
int modi = 0; //Modi: 0 = Normal Only Color with Truning, 1 = A constant rotating Pixel, 2 = colorWipes, 3 = rainbow, 4 = rainbowCycle, 5 = theaterChaseRainbow

//"Threads"
ThreadController controll = ThreadController();
Thread rainbowThread = Thread();
Thread rainbowCycleThread = Thread();
Thread colorWipeThread = Thread();

OneButton EncoderSwitch(SW,true);
Encoder meinEncoder(DT,CLK);  
Adafruit_NeoPixel pixels(NUMPIXELS, PIN, NEO_GRB + NEO_KHZ800);

void setup(){
  Serial.begin(9600);
  Consumer.begin();

  //Rotary Encoder with Switch
  pinMode(SW, INPUT);
  EncoderSwitch.attachClick(clickt);
  EncoderSwitch.attachDoubleClick(doubleclick);

  attachInterrupt(digitalPinToInterrupt(SW), checkTicks, CHANGE);
  //attachInterrupt(digitalPinToInterrupt(CLK), checkTicks, CHANGE);

  //LEDs
  pixels.begin();

  //"Threads" to run the LEDs while using the Rotary Encoder
  rainbowThread.onRun(rainbow);
  rainbowThread.setInterval(250);

  rainbowCycleThread.onRun(rainbowCycle);
  rainbowCycleThread.setInterval(500);

  colorWipeThread.onRun(colorWipe);
  colorWipeThread.setInterval(350);

  //Add the threads to the controller
  controll.add(&rainbowThread);
  controll.add(&rainbowCycleThread);
  controll.add(&colorWipeThread);
}

void loop(){
  
  if(menue == 0){
    ChangeVolume();
  }
  else if (menue == 1)  {
    ChangeMainColor();
  }
  else if (menue == 2) {
    ChangeModi();
  }
  
  EncoderSwitch.tick();
  if(modi != 0){
    controll.run();
  }
}

void checkTicks()
{
  EncoderSwitch.tick();
}

void clickt() {
  if(menue == 0){
    Serial.println("Mute"); 
    Consumer.write(MEDIA_VOL_MUTE);
    lightAllFade(1500);
  }
  if(menue == 1) {
    Serial.println("Switch to Normal-Modus");
    row = selected;
    menue = 0;
  }
  if(menue == 2){
    menue = 0;
  }
}

void doubleclick() {
  if(menue == 0){
    Serial.println("\nOpen Settings-Color");
    modi = 0;
    pixels.clear();
    menue = 1;
    selected = row;
  }else if(menue == 1) {
    pixels.clear();
    pixels.show();
    menue = 2;
    Serial.println("Switch to Modi-Menu");
  }else if(menue == 2) {
    Serial.print("Leave Settings");
    modi = 0;
    menue = 0;
  }
}

void ChangeVolume() {
  long neuePosition = meinEncoder.read();   //read the position of the encoder
  if (neuePosition != altePosition){    
    Serial.print(neuePosition);
    pixels.setPixelColor(pos, pixels.Color(color[row][0], color[row][1], color[row][2]));
    brightness = 255;
    pixels.setBrightness(255);
    pixels.show();   // Send the updated pixel colors to the hardware.
    if(neuePosition < altePosition){      //if the wheel turns left
        Consumer.write(MEDIA_VOL_UP);
        if(timer1){
          pos--;
          if(pos < 0){
            pos = 7;
          }        
          timer1 = false;
        }else {
          timer1 = true;
        }
    }else {   
        Consumer.write(MEDIA_VOL_DOWN);
        if(timer2){
          pos++;
          if(pos == 8){
            pos = 0;
          }
          timer2 = false;
        }else{
          timer2 = true;
        }
    } 
    pixels.clear(); // Set all pixel colors to 'off'   
    myTimer = millis();
    altePosition = neuePosition;    
  }
  if (millis() > myTimeout + myTimer) {   //turns of the Led that was turned on off after the timer ends
    myTimer = millis();
    pixels.clear();
    pixels.show();
  }
}

void ChangeMainColor(){
  long neuePosition = meinEncoder.read();   //read the position of the encoder
  lightAll();
  if (neuePosition != altePosition){    
    //Serial.print(neuePosition);
    if(neuePosition < altePosition){      //if the wheel turns left
        if(timer1){
          selected--;
          if(selected < 0){
            selected = 24;
          }        
          timer1 = false;
        }else {
          timer1 = true;
        }
    }else {   
        if(timer2){
          selected++;
          if(selected == 25){
            selected = 0;
          }
          timer2 = false;
        }else{
          timer2 = true;
        }
    } 
    altePosition = neuePosition;    
  }
}

void ChangeModi(){
  long neuePosition = meinEncoder.read();   //read the position of the encoder
  Serial.print("Selected Modi: ");
  Serial.println(modi);
  if (neuePosition != altePosition){    
    Serial.print(neuePosition);
    if(neuePosition > altePosition){      //if the wheel turns left
        if(timer1){
          modi--;
          if(modi < 0){
            modi = 5;
          }
          else if (modi > 5){
            modi = 0;        
          }
          timer1 = false;
        }else {
          timer1 = true;
        }
    }else {   
        if(timer2){
          modi++;
          if(modi >= 6){
            selected = 0;
          }
          timer2 = false;
        }else{
          timer2 = true;
        }
    } 
    altePosition = neuePosition;    
  }
}

void lightAll(){ //Used in the Colorselection-menu
  pixels.clear();
  for(int i = 0; i < 9; i++) {
    pixels.setPixelColor(i, pixels.Color(color[selected][0], color[selected][1], color[selected][2]));
  }
  brightness = 255;
  pixels.setBrightness(255);
  pixels.show();
}

void lightAllFade(int sec) {
  for(int i = 0; i < NUMPIXELS; i++){
    pixels.setPixelColor(i, pixels.Color(color[row][0], color[row][1], color[row][2]));
  }
  pixels.setBrightness(255);
  pixels.show();   // Send the updated pixel colors to the hardware.
  for(int i = 255; i>0; i--){
    pixels.setBrightness(i);
    pixels.show();
    delay(sec/255);
  }
  pixels.setBrightness(255);
  pixels.clear();
}

void rotatingPixel(){
  if(modi == 1) {
    
  }
}
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

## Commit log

2021-12-14 Completly new structur
    The second version had all going and made it difficult to show rainbow colors with full controll of the button and the rotary encoder. I also tried pseudo "Threads", but they doesn't work and were hell of a mess. Here I tried to use a structure to use one Array that always get updated to the LEDs after a loop ended. It's also easier to understand what the system is doing. So if I want to be in rainbow mod I can update the Arrays for the LEDs for the next round let the controller set the LEDs and still have the controll of Button and Rotary Encoder.
    [volumeKnob.ino]
2021-12-17 Added Menu better controls
    You can chose a mode and many bugs are fixed. Two new modes with rainbow-colors.
    [volumeKnob.ino]
2021-12-19 New Mode
    From 0 to 33 percent Volume the LEDs are green, from 34 till 66 the LEDs are yellow and the rest are red.
2021-12-19 Added a new mode
    You spin, 3 LEDs move and stay always on
2022-02-25 Changed PCB Layout // Changes to code
    Fixed static LED Numbers
    [ARDUINO PRO MICROCool.iam, ArduinoProMicroButtomSoldered.0001.iam, ArduinoProMicroButtomSoldered.iam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]
2022-03-02 moved .ino file to an extra folder for arduino ide
2022-03-25 New rotary knob with a Pause/Play symbol
    [DrehreglerWithPause.stl, PCB-Holder.stl, Pause.ipt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]
